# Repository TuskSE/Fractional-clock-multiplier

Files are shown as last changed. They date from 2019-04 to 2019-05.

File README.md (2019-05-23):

# Fractional Clock Multiplier (wip)
8hp algorithmic rhythm-generation module for Eurorack, powered by the Teensy LC

Currently two main modes:
* Fractional Multiplication and division of steady or slowly-varying clock inputs.
  * No requirement for clock input to be multiple ppqn, as the clock input is predictive. I'd like to update this so it can deal with swung input also
* Generation of euclidean rhythms ( see [Toussaint 2005](http://cgm.cs.mcgill.ca/~godfried/publications/banff.pdf) ) from arbitrary (regular or non-regular) clock input 

Output can be shifted either by beat-quantized or subquantized amounts, and optionally recombined with the input. This can be used to generate swung clock output for example, or controlled via CV to generate complex compound rhythms. 

Selectable trigger/gate output modes. 

Assignable CV control over all paramaters, with attenuverter. 

Current schematic, panel mockup and PCB design:

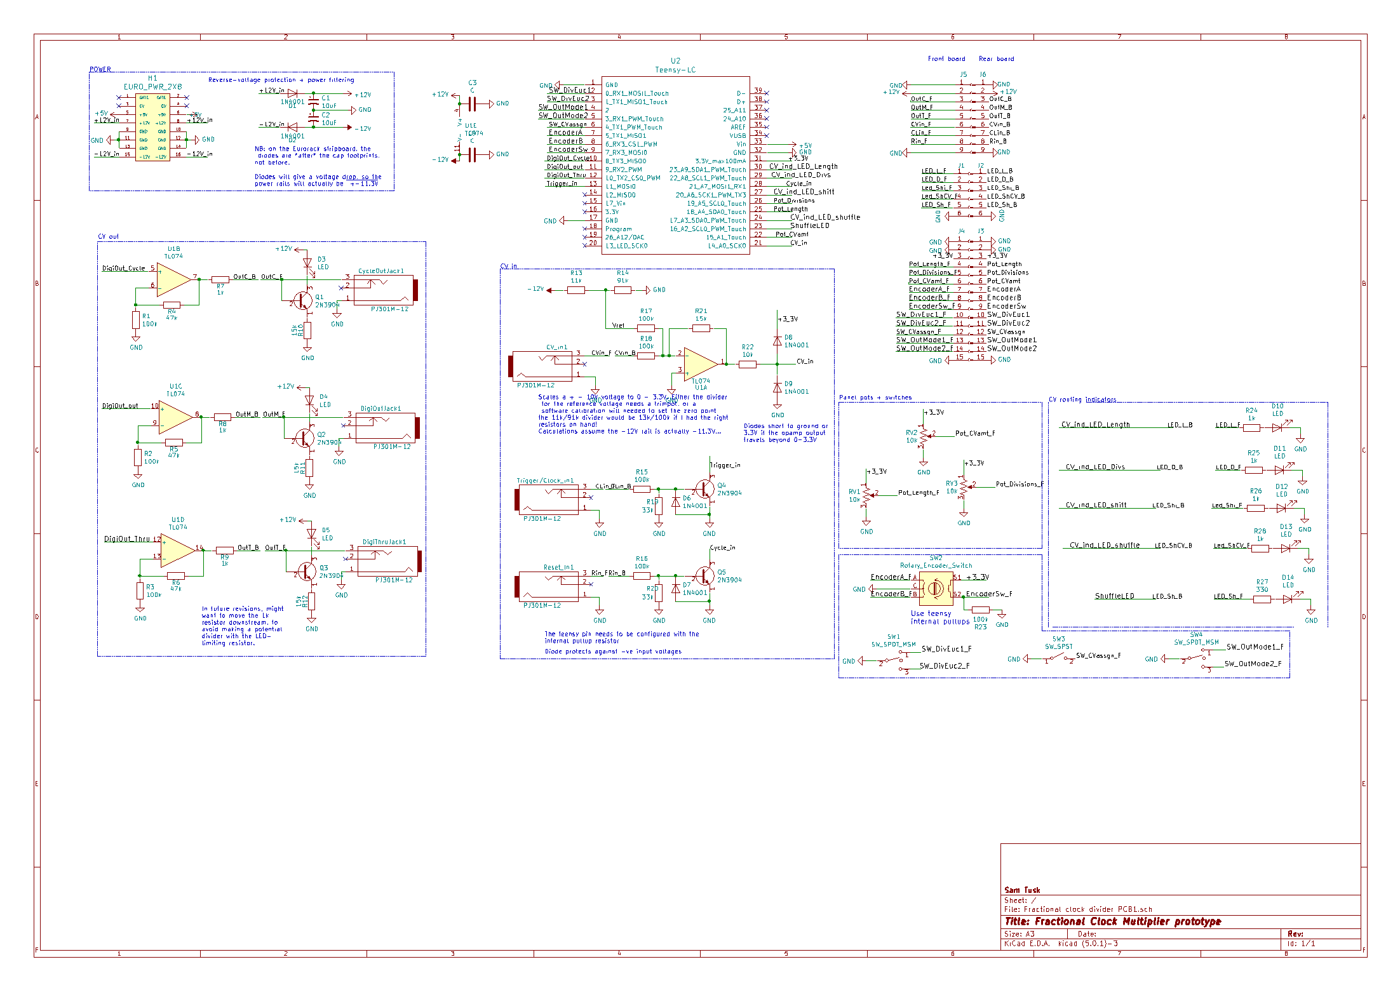
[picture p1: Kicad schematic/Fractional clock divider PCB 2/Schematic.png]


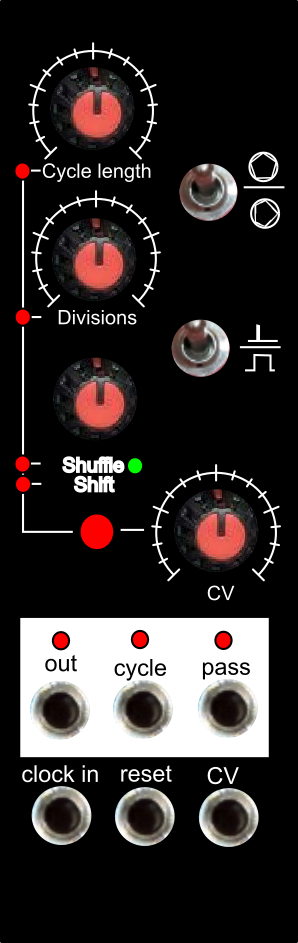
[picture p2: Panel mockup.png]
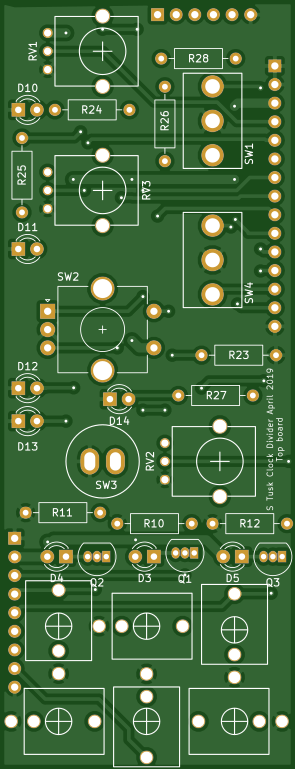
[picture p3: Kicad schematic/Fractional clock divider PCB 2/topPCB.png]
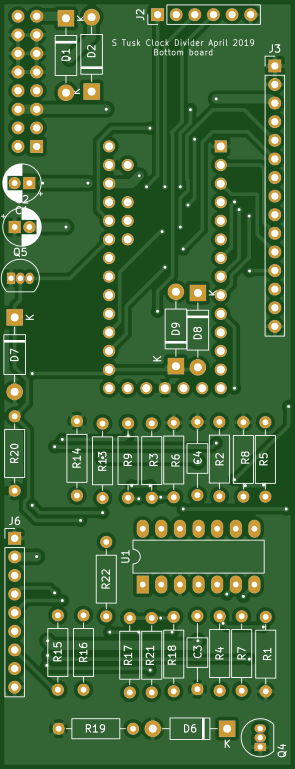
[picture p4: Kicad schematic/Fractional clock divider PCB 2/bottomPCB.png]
   

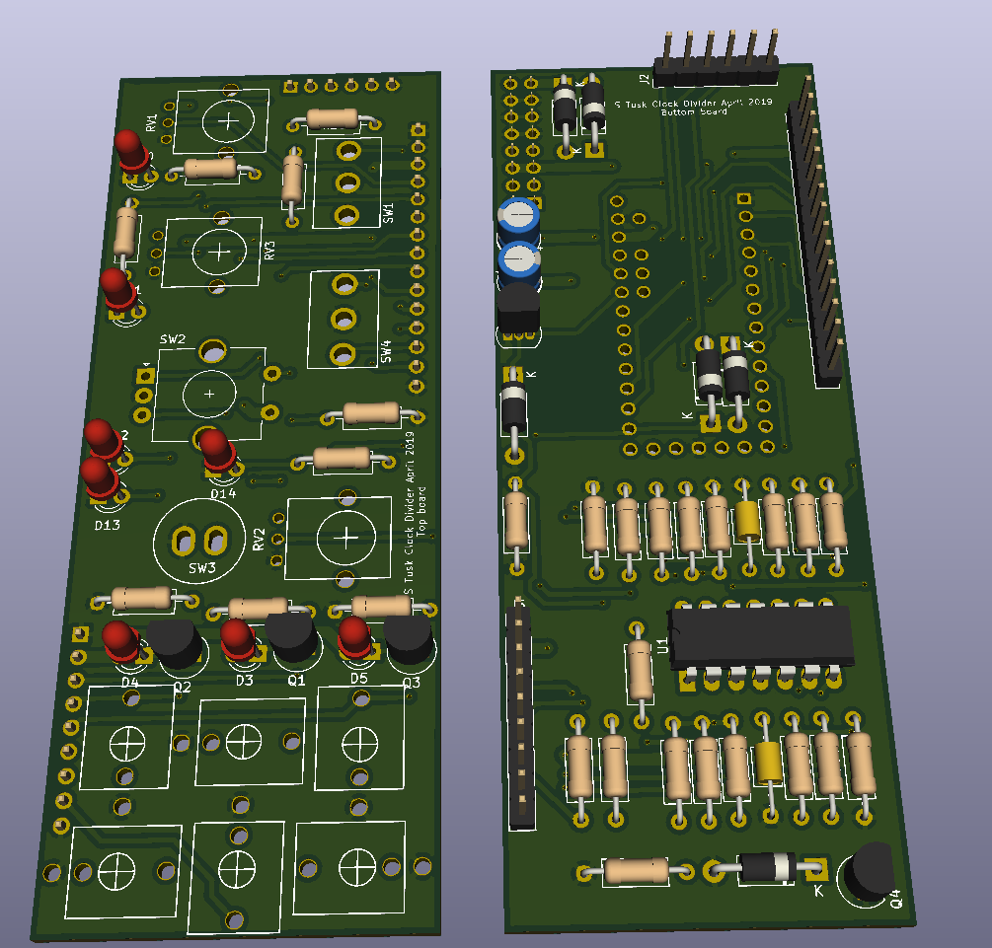
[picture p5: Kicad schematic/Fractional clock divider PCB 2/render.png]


An older prototype:

 


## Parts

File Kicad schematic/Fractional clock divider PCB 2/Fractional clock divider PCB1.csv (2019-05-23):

Id | Designator | Package | Quantity | Designation | Supplier and ref
1 | , | KnobTicks | 2
2 | ,,,, | 9mm alpha jack hole | 5 | 9mm alpha jack hole
3 | ,REF**,REF**,,,,,, | Eurorack Rail Hole | 9 | Eurorack Rail Hole
4 | ,,,,,,, | Eurorack jack hole | 8 | Eurorack jack hole
5 |  | Eurorack LED hole | 1 | Eurorack LED hole
6 | CV_in1,Reset_In1,Trigger/Clock_in1,DigiThruJack1,CycleOutJack1,DigiOutJack1 | PJ301M-12-MoreMetal | 6 | PJ301M-12
7 | Q3,Q1,Q2,Q4,Q5 | TO-92L_HandSolder | 5 | 2N3904
8 | C4,C3 | C_Axial_L3.8mm_D2.6mm_P10.00mm_Horizontal | 2 | 100nF
9 | RV1,RV2,RV3 | Alpha9mmPot | 3 | 10k
10 | R27 | R_Axial_DIN0207_L6.3mm_D2.5mm_P10.16mm_Horizontal | 1 | 330
11 | C1,C2 | CP_Radial_D5.0mm_P2.00mm | 2 | 10uF
12 | D1,D2,D6,D7,D8,D9 | D_DO-41_SOD81_P10.16mm_Horizontal | 6 | 1N4001
13 | D3,D4,D5,D10,D11,D12,D13,D14 | LED_D3.0mm | 8 | LED
14 | H1 | PinSocket_2x08_P2.54mm_Vertical | 1 | EURO_PWR_2X8
15 | J1 | PinHeader_1x06_P2.54mm_Vertical | 1 | Conn_01x06_Female
16 | J2 | PinHeader_1x06_P2.54mm_Vertical | 1 | Conn_01x06_Male
17 | J3 | PinHeader_1x15_P2.54mm_Vertical | 1 | Conn_01x15_Male
18 | J4 | PinHeader_1x15_P2.54mm_Vertical | 1 | Conn_01x15_Female
19 | J5 | PinHeader_1x09_P2.54mm_Vertical | 1 | Conn_01x09_Female
20 | J6 | PinHeader_1x09_P2.54mm_Vertical | 1 | Conn_01x09_Male
21 | R1,R2,R3,R15,R16,R17,R18,R23 | R_Axial_DIN0207_L6.3mm_D2.5mm_P10.16mm_Horizontal | 8 | 100k
22 | R4,R5,R6 | R_Axial_DIN0207_L6.3mm_D2.5mm_P10.16mm_Horizontal | 3 | 47k
23 | R7,R8,R9,R24,R25,R26,R28 | R_Axial_DIN0207_L6.3mm_D2.5mm_P10.16mm_Horizontal | 7 | 1k
24 | R10,R11,R12,R22 | R_Axial_DIN0207_L6.3mm_D2.5mm_P10.16mm_Horizontal | 4 | 10k
25 | R13 | R_Axial_DIN0207_L6.3mm_D2.5mm_P10.16mm_Horizontal | 1 | 11k
26 | R14 | R_Axial_DIN0207_L6.3mm_D2.5mm_P10.16mm_Horizontal | 1 | 91k
27 | R19,R20 | R_Axial_DIN0207_L6.3mm_D2.5mm_P10.16mm_Horizontal | 2 | 33k
28 | R21 | R_Axial_DIN0207_L6.3mm_D2.5mm_P10.16mm_Horizontal | 1 | 15k
29 | SW1,SW4 | SPDT toggle on-off-on | 2 | SW_SPDT_MSM
30 | SW2 | RotaryEncoder_Alps_EC11E-Switch_Vertical_H20mm_CircularMountingHoles | 1 | Rotary_Encoder_Switch
31 | SW3 | SPST momentary push PBS105 | 1 | SW_SPST
32 | U1 | DIP-14_W7.62mm_LongPads | 1 | TL074
33 | U2 | TeensyLC_fixed_pads | 1 | Teensy-LC

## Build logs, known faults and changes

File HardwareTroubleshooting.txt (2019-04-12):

Trigger outs:
- cycle out LED doesn't work, but trigger outs all produce a voltage. The voltage is ~4.88V; will have to check at some point whether this is sufficient for triggering most modules. 

Trig IN triggers much too easily (even with zero input voltage). Tracked down to missing ground collection on the transistor base!

CV in works ok, although at high voltage it starts to clip. I think the offset can be moved, because there's room at the other end of the range. Maybe use a trimmer for the final circuit...

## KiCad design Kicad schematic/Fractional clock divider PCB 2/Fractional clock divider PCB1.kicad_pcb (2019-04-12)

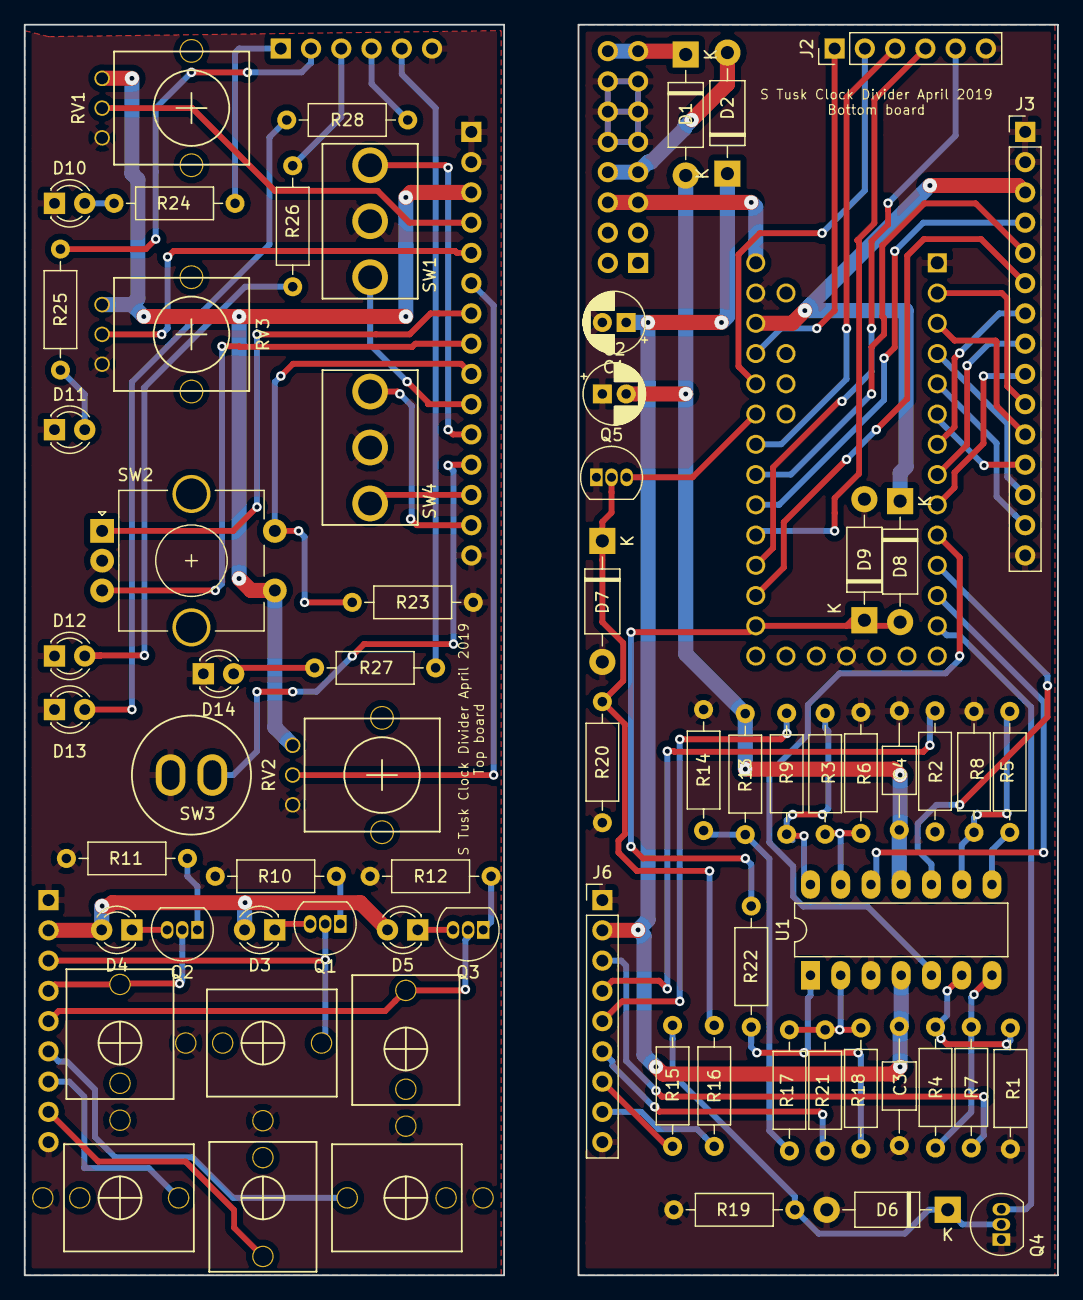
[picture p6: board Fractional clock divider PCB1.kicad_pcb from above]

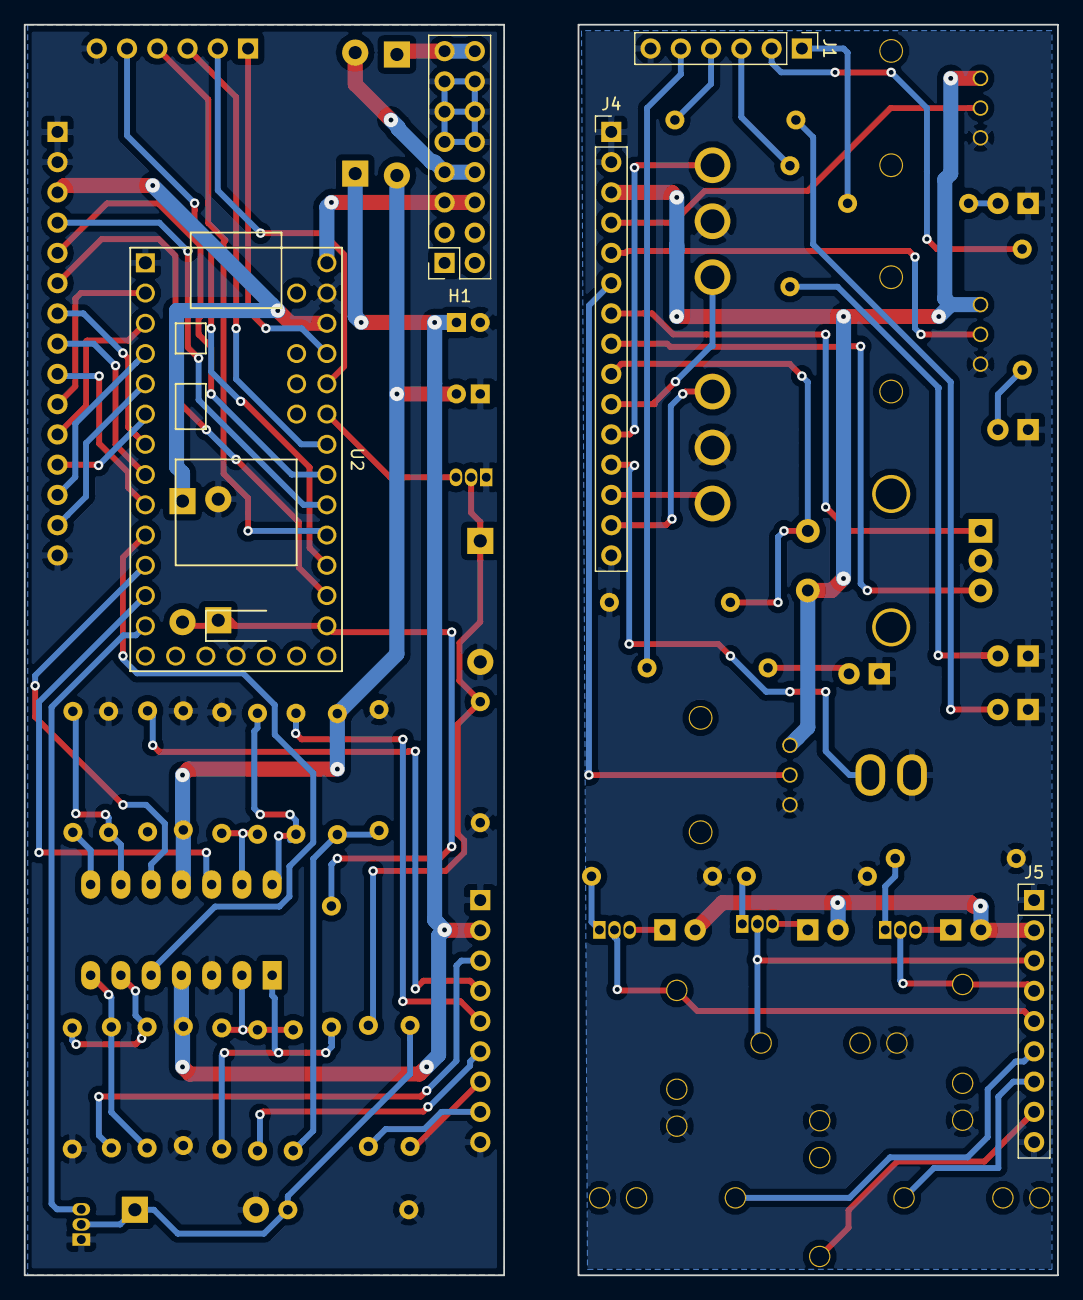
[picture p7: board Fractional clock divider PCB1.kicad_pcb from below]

Board: 2 copper layers, 86.8 x 105.0 mm, 73 parts (5 on the bottom side), 79 nets.

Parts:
C1, C2: 10uF; CP_Radial_D5.0mm_P2.00mm
C3, C4: C; C_Axial_L3.8mm_D2.6mm_P10.00mm_Horizontal
CV_in1: PJ301M-12
CycleOutJack1: PJ301M-12
D1, D2, D6, D7, D8, D9: 1N4001; D_DO-41_SOD81_P10.16mm_Horizontal
D3, D4, D5, D10, D11, D12, D13, D14: LED; LED_D3.0mm
DigiOutJack1: PJ301M-12
DigiThruJack1: PJ301M-12
H1: EURO_PWR_2X8; PinSocket_2x08_P2.54mm_Vertical
J1: Conn_01x06_Female; PinHeader_1x06_P2.54mm_Vertical
J2: Conn_01x06_Male; PinHeader_1x06_P2.54mm_Vertical
J3: Conn_01x15_Male; PinHeader_1x15_P2.54mm_Vertical
J4: Conn_01x15_Female; PinHeader_1x15_P2.54mm_Vertical
J5: Conn_01x09_Female; PinHeader_1x09_P2.54mm_Vertical
J6: Conn_01x09_Male; PinHeader_1x09_P2.54mm_Vertical
Q1, Q2, Q3, Q4, Q5: 2N3904; TO-92_Inline
R1, R2, R3, R15, R16, R17, R18, R23: 100k; R_Axial_DIN0207_L6.3mm_D2.5mm_P10.16mm_Horizontal
R4, R5, R6: 47k; R_Axial_DIN0207_L6.3mm_D2.5mm_P10.16mm_Horizontal
R7, R8, R9, R24, R25, R26, R28: 1k; R_Axial_DIN0207_L6.3mm_D2.5mm_P10.16mm_Horizontal
R10, R11, R12, R21: 15k; R_Axial_DIN0207_L6.3mm_D2.5mm_P10.16mm_Horizontal
R13: 11k; R_Axial_DIN0207_L6.3mm_D2.5mm_P10.16mm_Horizontal
R14: 91k; R_Axial_DIN0207_L6.3mm_D2.5mm_P10.16mm_Horizontal
R19, R20: 33k; R_Axial_DIN0207_L6.3mm_D2.5mm_P10.16mm_Horizontal
R22: 10k; R_Axial_DIN0207_L6.3mm_D2.5mm_P10.16mm_Horizontal
R27: 330; R_Axial_DIN0207_L6.3mm_D2.5mm_P10.16mm_Horizontal
RV1, RV2, RV3: 10k; Alpha9mmPot
Reset_In1: PJ301M-12
SW1, SW4: SW_SPDT_MSM; SPDT toggle on-off-on
SW2: Rotary_Encoder_Switch; RotaryEncoder_Alps_EC11E-Switch_Vertical_H20mm_CircularMoun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
SW3: SW_SPST; SPST momentary push PBS105
Trigger/Clock_in1: PJ301M-12
U1: TL074; DIP-14_W7.62mm_LongPads
U2: Teensy-LC; TeensyLC_fixed_pads

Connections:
+5V: H1.5, H1.6, U2.33
+12V: C1.1, C3.2, D1.1, D3.2, D4.2, D5.2, J5.2, J6.2, U1.4
-12V: C2.2, C4.1, D2.2, R13.2, U1.11
/+3_3V: D8.1, J3.3, J4.3, RV1.1, RV2.1, RV3.1, SW2.S1, U2.31
/+12V_in: D1.2, H1.7, H1.8
/-12V_in: D2.1, H1.15, H1.16
/CLin_B: J6.7, R15.2
/CLin_F: J5.7, Trigger/Clock_in1.3
/CV_in: D8.2, D9.1, R22.1, U2.21
/CV_ind_LED_Divs: J2.2, U2.29
/CV_ind_LED_Length: J2.1, U2.30
/CV_ind_LED_shift: J2.3, U2.27
/CV_ind_LED_shuffle: J2.4, U2.24
/CVin_B: J6.6, R18.2
/CVin_F: CV_in1.3, J5.6
/Cycle_in: Q5.3, U2.28
/DigiOut_Cycle: U1.5, U2.10
/DigiOut_Thru: U1.12, U2.12
/DigiOut_out: U1.10, U2.11
/EncoderA: J3.7, U2.7
/EncoderA_F: J4.7, SW2.A
/EncoderB: J3.8, U2.8
/EncoderB_F: J4.8, SW2.B
/EncoderSw: J3.9, U2.9
/EncoderSw_F: J4.9, R23.1, SW2.S2
/LED_D_F: J1.2, R25.2
/LED_L_F: J1.1, R24.2
/LED_Sh_B: J2.5, U2.23
/LED_Sh_F: J1.5, R27.2
/Led_ShCV_F: J1.4, R28.2
/Led_Shi_F: J1.3, R26.2
/OutC_B: J6.3, R7.1
/OutC_F: CycleOutJack1.3, J5.3, Q1.2
/OutM_B: J6.4, R8.1
/OutM_F: DigiOutJack1.3, J5.4, Q2.2
/OutT_B: J6.5, R9.1
/OutT_F: DigiThruJack1.3, J5.5, Q3.2
/Pot_CVamt: J3.6, U2.22
/Pot_CVamt_F: J4.6, RV2.2
/Pot_Divisions: J3.5, U2.26
/Pot_Divisions_F: J4.5, RV3.2
/Pot_Length: J3.4, U2.25
/Pot_Length_F: J4.4, RV1.2
/Rin_B: J6.8, R16.2
/Rin_F: J5.8, Reset_In1.3
/SW_CVassgn: J3.12, U2.6
/SW_CVassgn_F: J4.12, SW3.2
/SW_DivEuc1: J3.10, U2.2
/SW_DivEuc1_F: J4.10, SW1.1
/SW_DivEuc2: J3.11, U2.3
/SW_DivEuc2_F: J4.11, SW1.3
/SW_OutMode1: J3.13, U2.4
/SW_OutMode1_F: J4.13, SW4.1
/SW_OutMode2: J3.14, U2.5
/SW_OutMode2_F: J4.14, SW4.3
/Trigger_in: Q4.3, U2.13
/Vref: R13.1, R14.2, R17.2
GND: C1.2, C2.1, C3.1, C4.2, CV_in1.1, CycleOutJack1.1, D6.2, D7.2, D9.2, D10.1, D11.1, D12.1, D13.1, D14.1, DigiOutJack1.1, DigiThruJack1.1, H1.9, H1.10, H1.11, H1.12, H1.13, H1.14, J1.6, J2.6, J3.1, J3.2, J3.15, J4.1, J4.2, J4.15, J5.1, J5.9, J6.1, J6.9, Q4.1, Q5.1, R1.2, R2.2, R3.2, R10.1, R11.1, R12.1, R14.1, R19.1, R20.1, R23.2, RV1.3, RV2.3, RV3.3, Reset_In1.1, SW1.2, SW2.C, SW3.1, SW4.2, Trigger/Clock_in1.1, U1.3, U2.1, U2.17, U2.32
unnamed: D3.1, Q1.3
unnamed: D4.1, Q2.3
unnamed: D5.1, Q3.3
unnamed: D6.1, Q4.2, R15.1, R19.2
unnamed: D7.1, Q5.2, R16.1, R20.2
unnamed: D10.2, R24.1
unnamed: D11.2, R25.1
unnamed: D12.2, R26.1
unnamed: D13.2, R28.1
unnamed: D14.2, R27.1
unnamed: Q1.1, R10.2
unnamed: Q2.1, R11.2
unnamed: Q3.1, R12.2
unnamed: R1.1, R4.2, U1.6
unnamed: R2.1, R5.2, U1.9
unnamed: R3.1, R6.2, U1.13
unnamed: R4.1, R7.2, U1.7
unnamed: R5.1, R8.2, U1.8
unnamed: R6.1, R9.2, U1.14
unnamed: R17.1, R18.1, R21.2, U1.2
unnamed: R21.1, R22.2, U1.1

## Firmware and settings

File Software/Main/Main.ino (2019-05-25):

#include <Metro.h> // Include the Metro library
#include <Encoder.h>
const int KnobCalibrateMode = 0;

//Define all the pins
const int SwPin_DivEuc = 0;  // Low input = switch in upper position
const int SwPin_DivEuc2 = 1;   // Low input = switch in lower position
const int SwPin_OutModes = 2;   // Low input = switch in upper position
const int SwPin_OutModes2 = 3;  // Low input = switch in lower position
const int SwPin_CVassign = 4;   //Low input = switch pressed
const int SwPin_Encoder = 7;
const int CtrPin_CVamt = 15;
const int CtrPin_Divisions = 19;
const int CtrPin_Length = 18;
const int OutPin_Cycle = 8;
const int OutPin_MainOut = 9;
const int OutPin_Thru = 10;
const int InPin_Trig = 11; //Low input voltage = HIGH reading on pin.
const int InPin_CV = 14;
const int InPin_Reset = 21;
const int LEDPin_Shuffle = 16;
const int LEDPin_CV_ind_Length = 23;
const int LEDPin_CV_ind_Divs = 22;
const int LEDPin_CV_ind_Shift = 17;
const int LEDPin_CV_ind_Shuffle = 20;
//const int LEDPin_internal = 13;
const int EncPinA = 5;
const int EncPinB = 6;

//recentPresses[] stores the times of the 6 most recent switch presses
//[0] = most recent, [5] = most distant
// every time we write to this, shuffle the array around
double recentClockTimes[6] = {0,0,0,0,0,0}; 
const int recentClockTimesArraySize = 6;

const double ButtonPressTimeout = 5000000; //in microseconds. if the time between two button presses is greater than this, do not use it to set the output clock. 

//sets the range for the Length and Division knobs
const int Divisions_min = 0;
const int Divisions_max = 16;
const int Length_min = 0;
const int Length_max = 16;
//To read Knob value: reading = map(analogRead(CtrPin_Length),0,1023,Length_min,Length_max);
const int LengthKnobLUTDividers[] = {33, 177, 411, 667, 919, 1178, 1474, 1784, 2113, 2443, 2743, 3012, 3276, 3552, 3835, 4032, 2060};
int ControlVoltage_in = 0;
int ControlValue_Divisions, ControlValue_Divisions_Scaled = 1;
int ControlValue_Length, ControlValue_Length_Scaled =1;

double pressTimeTemp = 0; //temporarily stores the time, when the button is pressed
int clockInState = 0;
int clockInPrevState = 0; // this will remember if the clock input was "on" in the previous cycle 
int resetInState = 0;
int resetInPrevState = 0;

//multiplication/division factors. These will eventually be controlled by pots.
//float ClicksPerCycle = 8;
float MultDivFactor2 = 2;
float MultDivFactor3 = 0.5;

Encoder EncKnob(EncPinB, EncPinA);
int EncoderValTemp = 0;
int EncoderShiftInstruction = 0; 
int intEncoderShuffleInstruction = 0;
float EncoderShuffleInstruction = 0.0;
const int EncoderCountsPerClick = 4; //property of the encoder used: how many digital output counts corresponding to one click (indent) felt by the user.
//const int EncoderClicksPerRevolution = 20; //property of the encoder used 
int EncoderShuffleNoOfClicks = 20; //The number of clicks of encoder rotation which makes the shuffle amount return to it's starting value
const int EncoderShuffleLedLUT[] = {0, 1, 1, 2, 3, 4, 5, 6, 7, 8, 9, 11, 13, 15, 17, 20, 23, 25, 30, 30, 20}; 
int intShuffleCVInstruction = 0;
int ShiftCVInstruction = 0;

bool CVcontrolCycleLength, CVcontrolDivisions, CVcontrolShuffle, CVcontrolShift;

bool EuclideanMode_temp = true; //if 0, runs as clock divider. If 1, runs as euclidean pattern generator. 

int Temp;

//lookup tables for pot readings
const int LUT_L[] = {120,120,120,120,120,120,120,120,120,120,120,120,120,120,120,120,120,120,120,120,120,120,120,120,120,120,120,361,361,361,361,361,361,361,361,361,361,361,361,361,361,361,361,361,361,361,361,361,361,361,361,361,361,361,361,361,361,361,361,361,361,361,361,361,361,361,361,361,361,361,361,361,361,361,361,361,361,361,361,361,361,361,361,361,361,361,361,361,361,361,361,361,361,361,361,361,361,361,361,361,361,361,361,361,361,361,361,361,361,361,361,361,361,361,361,361,361,361,361,361,361,361,361,361,361,361,361,361,361,361,361,361,361,361,361,361,361,361,361,361,361,361,361,361,602,602,602,602,602,602,602,602,602,602,602,602,602,602,602,602,602,602,602,602,602,602,602,602,602,602,602,602,602,602,602,602,602,602,602,602,602,602,602,602,602,602,602,602,602,602,602,602,602,602,602,602,602,602,602,602,602,602,602,602,602,602,602,602,602,602,602,602,602,602,602,602,602,602,602,602,602,602,602,602,602,602,602,602,602,602,602,602,602,602,602,602,602,602,602,602,602,602,602,602,602,602,602,602,602,602,602,602,602,602,602,602,602,602,602,602,602,602,602,602,602,602,602,602,602,602,602,602,602,602,602,602,602,602,602,602,602,602,602,602,602,602,602,602,602,602,602,602,602,602,602,602,602,602,602,602,602,602,602,602,602,602,602,602,602,602,602,602,602,602,602,602,602,602,602,602,602,602,602,602,602,602,602,602,602,602,602,602,602,602,602,602,602,602,602,602,602,602,602,602,602,602,602,602,602,602,602,602,602,602,602,602,602,602,602,602,602,602,602,602,602,602,602,602,602,602,602,602,602,602,602,602,602,602,843,843,843,843,843,843,843,843,843,843,843,843,843,843,843,843,843,843,843,843,843,843,843,843,843,843,843,843,843,843,843,843,843,843,843,843,843,843,843,843,843,843,843,843,843,843,843,843,843,843,843,843,843,843,843,843,843,843,843,843,843,843,843,843,843,843,843,843,843,843,843,843,843,843,843,843,843,843,843,843,843,843,843,843,843,843,843,843,843,843,843,843,843,843,843,843,843,843,843,843,843,843,843,843,843,843,843,843,843,843,843,843,843,843,843,843,843,843,843,843,843,843,843,843,843,843,843,843,843,843,843,843,843,843,843,843,843,843,843,843,843,843,843,843,843,843,843,843,843,843,843,843,843,843,843,843,843,843,843,843,843,843,843,843,843,843,843,843,843,843,843,843,843,843,843,843,843,843,843,843,843,843,843,843,843,843,843,843,843,843,843,843,843,843,843,843,843,843,843,843,843,843,843,843,843,843,843,843,843,843,843,843,843,843,843,843,843,843,843,843,843,843,843,843,843,843,843,843,843,843,843,843,843,843,843,843,843,843,843,843,843,843,843,843,843,843,843,843,843,843,843,843,843,843,843,843,843,843,843,843,843,843,843,843,843,843,843,843,843,843,843,843,843,1084,1084,1084,1084,1084,1084,1084,1084,1084,1084,1084,1084,1084,1084,1084,1084,1084,1084,1084,1084,1084,1084,1084,1084,1084,1084,1084,1084,1084,1084,1084,1084,1084,1084,1084,1084,1084,1084,1084,1084,1084,1084,1084,1084,1084,1084,1084,1084,1084,1084,1084,1084,1084,1084,1084,1084,1084,1084,1084,1084,1084,1084,1084,1084,1084,1084,1084,1084,1084,1084,1084,1084,1084,1084,1084,1084,1084,1084,1084,1084,1084,1084,1084,1084,1084,1084,1084,1084,1084,1084,1084,1084,1084,1084,1084,1084,1084,1084,1084,1084,1084,1084,1084,1084,1084,1084,1084,1084,1084,1084,1084,1084,1084,1084,1084,1084,1084,1084,1084,1084,1084,1084,1084,1084,1084,1084,1084,1084,1084,1084,1084,1084,1084,1084,1084,1084,1084,1084,1084,1084,1084,1084,1084,1084,1084,1084,1084,1084,1084,1084,1084,1084,1084,1084,1084,1084,1084,1084,1084,1084,1084,1084,1084,1084,1084,1084,1084,1084,1084,1084,1084,1084,1084,1084,1084,1084,1084,1084,1084,1084,1084,1084,1084,1084,1084,1084,1084,1084,1084,1084,1084,1084,1084,1084,1084,1084,1084,1084,1084,1084,1084,1084,1084,1084,1084,1084,1084,1084,1084,1084,1084,1084,1084,1084,1084,1084,1084,1084,1084,1084,1084,1084,1084,1084,1084,1084,1084,1084,1084,1084,1084,1084,1084,1084,1084,1084,1084,1084,1084,1084,1084,1084,1084,1084,1084,1084,1084,1084,1084,1084,1084,1084,1084,1084,1084,1084,1084,1084,1084,1084,1084,1325,1325,1325,1325,1325,1325,1325,1325,1325,1325,1325,1325,1325,1325,1325,1325,1325,1325,1325,1325,1325,1325,1325,1325,1325,1325,1325,1325,1325,1325,1325,1325,1325,1325,1325,1325,1325,1325,1325,1325,1325,1325,1325,1325,1325,1325,1325,1325,1325,1325,1325,1325,1325,1325,1325,1325,1325,1325,1325,1325,1325,1325,1325,1325,1325,1325,1325,1325,1325,1325,1325,1325,1325,1325,1325,1325,1325,1325,1325,1325,1325,1325,1325,1325,1325,1325,1325,1325,1325,1325,1325,1325,1325,1325,1325,1325,1325,1325,1325,1325,1325,1325,1325,1325,1325,1325,1325,1325,1325,1325,1325,1325,1325,1325,1325,1325,1325,1325,1325,1325,1325,1325,1325,1325,1325,1325,1325,1325,1325,1325,1325,1325,1325,1325,1325,1325,1325,1325,1325,1325,1325,1325,1325,1325,1325,1325,1325,1325,1325,1325,1325,1325,1325,1325,1325,1325,1325,1325,1325,1325,1325,1325,1325,1325,1325,1325,1325,1325,1325,1325,1325,1325,1325,1325,1325,1325,1325,1325,1325,1325,1325,1325,1325,1325,1325,1325,1325,1325,1325,1325,1325,1325,1325,1325,1325,1325,1325,1325,1325,1325,1325,1325,1325,1325,1325,1325,1325,1325,1325,1325,1325,1325,1325,1325,1325,1325,1325,1325,1325,1325,1325,1325,1325,1325,1325,1325,1325,1325,1325,1325,1325,1325,1325,1325,1325,1325,1325,1325,1325,1325,1325,1325,1325,1325,1325,1325,1325,1325,1325,1325,1325,1325,1325,1325,1325,1325,1325,1325,1325,1325,1325,1325,1325,1325,1325,1325,1566,1566,1566,1566,1566,1566,1566,1566,1566,1566,1566,1566,1566,1566,1566,1566,1566,1566,1566,1566,1566,1566,1566,1566,1566,1566,1566,1566,1566,1566,1566,1566,1566,1566,1566,1566,1566,1566,1566,1566,1566,1566,1566,1566,1566,1566,1566,1566,1566,1566,1566,1566,1566,1566,1566,1566,1566,1566,1566,1566,1566,1566,1566,1566,1566,1566,1566,1566,1566,1566,1566,1566,1566,1566,1566,1566,1566,1566,1566,1566,1566,1566,1566,1566,1566,1566,1566,1566,1566,1566,1566,1566,1566,1566,1566,1566,1566,1566,1566,1566,1566,1566,1566,1566,1566,1566,1566,1566,1566,1566,1566,1566,1566,1566,1566,1566,1566,1566,1566,1566,1566,1566,1566,1566,1566,1566,1566,1566,1566,1566,1566,1566,1566,1566,1566,1566,1566,1566,1566,1566,1566,1566,1566,1566,1566,1566,1566,1566,1566,1566,1566,1566,1566,1566,1566,1566,1566,1566,1566,1566,1566,1566,1566,1566,1566,1566,1566,1566,1566,1566,1566,1566,1566,1566,1566,1566,1566,1566,1566,1566,1566,1566,1566,1566,1566,1566,1566,1566,1566,1566,1566,1566,1566,1566,1566,1566,1566,1566,1566,1566,1566,1566,1566,1566,1566,1566,1566,1566,1566,1566,1566,1566,1566,1566,1566,1566,1566,1566,1566,1566,1566,1566,1566,1566,1566,1566,1566,1566,1566,1566,1566,1566,1566,1566,1566,1566,1566,1566,1566,1566,1566,1566,1566,1566,1566,1566,1566,1566,1566,1566,1566,1566,1566,1566,1566,1566,1566,1566,1566,1566,1566,1566,1566,1566,1566,1566,1566,1566,1566,1566,1566,1566,1566,1566,1566,1566,1566,1566,1566,1566,1566,1566,1566,1566,1566,1566,1566,1566,1566,1566,1566,1807,1807,1807,1807,1807,1807,1807,1807,1807,1807,1807,1807,1807,1807,1807,1807,1807,1807,1807,1807,1807,1807,1807,1807,1807,1807,1807,1807,1807,1807,1807,1807,1807,1807,1807,1807,1807,1807,1807,1807,1807,1807,1807,1807,1807,1807,1807,1807,1807,1807,1807,1807,1807,1807,1807,1807,1807,1807,1807,1807,1807,1807,1807,1807,1807,1807,1807,1807,1807,1807,1807,1807,1807,1807,1807,1807,1807,1807,1807,1807,1807,1807,1807,1807,1807,1807,1807,1807,1807,1807,1807,1807,1807,1807,1807,1807,1807,1807,1807,1807,1807,1807,1807,1807,1807,1807,1807,1807,1807,1807,1807,1807,1807,1807,1807,1807,1807,1807,1807,1807,1807,1807,1807,1807,1807,1807,1807,1807,1807,1807,1807,1807,1807,1807,1807,1807,1807,1807,1807,1807,1807,1807,1807,1807,1807,1807,1807,1807,1807,1807,1807,1807,1807,1807,1807,1807,1807,1807,1807,1807,1807,1807,1807,1807,1807,1807,1807,1807,1807,1807,1807,1807,1807,1807,1807,1807,1807,1807,1807,1807,1807,1807,1807,1807,1807,1807,1807,1807,1807,1807,1807,1807,1807,1807,1807,1807,1807,1807,1807,1807,1807,1807,1807,1807,1807,1807,1807,1807,1807,1807,1807,1807,1807,1807,1807,1807,1807,1807,1807,1807,1807,1807,1807,1807,1807,1807,1807,1807,1807,1807,1807,1807,1807,1807,1807,1807,1807,1807,1807,1807,1807,1807,1807,1807,1807,1807,1807,1807,1807,1807,1807,1807,1807,1807,1807,1807,1807,1807,1807,1807,1807,1807,1807,1807,1807,1807,1807,1807,1807,1807,1807,1807,1807,1807,1807,1807,1807,1807,1807,1807,1807,1807,1807,1807,1807,1807,1807,1807,1807,1807,1807,1807,1807,1807,1807,1807,1807,1807,1807,1807,1807,1807,1807,1807,1807,1807,1807,1807,1807,1807,1807,1807,1807,1807,1807,1807,1807,1807,1807,1807,1807,1807,2048,2048,2048,2048,2048,2048,2048,2048,2048,2048,2048,2048,2048,2048,2048,2048,2048,2048,2048,2048,2048,2048,2048,2048,2048,2048,2048,2048,2048,2048,2048,2048,2048,2048,2048,2048,2048,2048,2048,2048,2048,2048,2048,2048,2048,2048,2048,2048,2048,2048,2048,2048,2048,2048,2048,2048,2048,2048,2048,2048,2048,2048,2048,2048,2048,2048,2048,2048,2048,2048,2048,2048,2048,2048,2048,2048,2048,2048,2048,2048,2048,2048,2048,2048,2048,2048,2048,2048,2048,2048,2048,2048,2048,2048,2048,2048,2048,2048,2048,2048,2048,2048,2048,2048,2048,2048,2048,2048,2048,2048,2048,2048,2048,2048,2048,2048,2048,2048,2048,2048,2048,2048,2048,2048,2048,2048,2048,2048,2048,2048,2048,2048,2048,2048,2048,2048,2048,2048,2048,2048,2048,2048,2048,2048,2048,2048,2048,2048,2048,2048,2048,2048,2048,2048,2048,2048,2048,2048,2048,2048,2048,2048,2048,2048,2048,2048,2048,2048,2048,2048,2048,2048,2048,2048,2048,2048,2048,2048,2048,2048,2048,2048,2048,2048,2048,2048,2048,2048,2048,2048,2048,2048,2048,2048,2048,2048,2048,2048,2048,2048,2048,2048,2048,2048,2048,2048,2048,2048,2048,2048,2048,2048,2048,2048,2048,2048,2048,2048,2048,2048,2048,2048,2048,2048,2048,2048,2048,2048,2048,2048,2048,2048,2048,2048,2048,2048,2048,2048,2048,2048,2048,2048,2048,2048,2048,2048,2048,2048,2048,2048,2048,2048,2048,2048,2048,2048,2048,2048,2048,2048,2048,2048,2048,2048,2048,2048,2048,2048,2048,2048,2048,2048,2048,2048,2048,2048,2048,2048,2048,2048,2048,2048,2048,2048,2048,2048,2048,2048,2048,2048,2048,2048,2048,2048,2048,2048,2048,2048,2048,2048,2048,2048,2048,2048,2048,2048,2048,2048,2048,2048,2048,2048,2048,2048,2048,2048,2048,2048,2048,2048,2048,2048,2048,2048,2048,2048,2048,2048,2289,2289,2289,2289,2289,2289,2289,2289,2289,2289,2289,2289,2289,2289,2289,2289,2289,2289,2289,2289,2289,2289,2289,2289,2289,2289,2289,2289,2289,2289,2289,2289,2289,2289,2289,2289,2289,2289,2289,2289,2289,2289,2289,2289,2289,2289,2289,2289,2289,2289,2289,2289,2289,2289,2289,2289,2289,2289,2289,2289,2289,2289,2289,2289,2289,2289,2289,2289,2289,2289,2289,2289,2289,2289,2289,2289,2289,2289,2289,2289,2289,2289,2289,2289,2289,2289,2289,2289,2289,2289,2289,2289,2289,2289,2289,2289,2289,2289,2289,2289,2289,2289,2289,2289,2289,2289,2289,2289,2289,2289,2289,2289,2289,2289,2289,2289,2289,2289,2289,2289,2289,2289,2289,2289,2289,2289,2289,2289,2289,2289,2289,2289,2289,2289,2289,2289,2289,2289,2289,2289,2289,2289,2289,2289,2289,2289,2289,2289,2289,2289,2289,2289,2289,2289,2289,2289,2289,2289,2289,2289,2289,2289,2289,2289,2289,2289,2289,2289,2289,2289,2289,2289,2289,2289,2289,2289,2289,2289,2289,2289,2289,2289,2289,2289,2289,2289,2289,2289,2289,2289,2289,2289,2289,2289,2289,2289,2289,2289,2289,2289,2289,2289,2289,2289,2289,2289,2289,2289,2289,2289,2289,2289,2289,2289,2289,2289,2289,2289,2289,2289,2289,2289,2289,2289,2289,2289,2289,2289,2289,2289,2289,2289,2289,2289,2289,2289,2289,2289,2289,2289,2289,2289,2289,2289,2289,2289,2289,2289,2289,2289,2289,2289,2289,2289,2289,2289,2289,2289,2289,2289,2289,2289,2289,2289,2289,2289,2289,2289,2289,2289,2289,2289,2289,2289,2289,2289,2289,2289,2289,2289,2289,2289,2289,2289,2289,228
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
void loop() {

  //calibrate mode only
  if(KnobCalibrateMode == 1){
      KnobCalibrator LengthKnobCalibrator, DivsKnobCalibrator;
      LengthKnobCalibrator.SetKnobPin(CtrPin_Length);
      DivsKnobCalibrator.SetKnobPin(CtrPin_Divisions);
      Serial.println("Length knob:");
      LengthKnobCalibrator.RecordCalibrationValues();
      Serial.println("Divs knob:");
      DivsKnobCalibrator.RecordCalibrationValues();
  }

  //Check mode
  ModeControllerMaster.ReadModeSwitch();
  ModeControllerMaster.ReadGateSwitch();
  
  // deal with reset input
  resetInState = digitalRead(InPin_Reset);
  if(resetInState == 0 && resetInPrevState == 1){      //............if the Reset In voltage switches from low to high
    //pass to whatever's controlling the current output mode
      EuclideanCalculatorMain.CycleReset();
      DividerMultiplierMain.CycleReset();
  }
    resetInPrevState = resetInState;    
    
  // deal with clock input
  clockInState = digitalRead(InPin_Trig);
  if(clockInState == 0 && clockInPrevState == 1){      //............if the Trigger In voltage switches from low to high
    //pass to the pulse predictor
    InputPulsePredictor.InputPulse();

    //pass to the output calculators
      EuclideanCalculatorMain.InputPulse();
      DividerMultiplierMain.InputPulse();
  }
    clockInPrevState = clockInState;



  


  //update knob control values
  //we repeat the reading twice, because if we take the first reading, it will still have some residual influence from the previous reading because the capacitor hasn't had time to charge/discharge. 
  ControlValue_Length = analogRead(CtrPin_Length);
  //ControlValue_Length = JitterSmootherL.SmoothChanges(analogRead(CtrPin_Length));
  ControlValue_Length = LUT_L[JitterSmootherL.SmoothChanges(analogRead(CtrPin_Length))];
  ControlValue_Divisions = analogRead(CtrPin_Divisions);
  //ControlValue_Divisions = JitterSmootherD.SmoothChanges(analogRead(CtrPin_Divisions));
  ControlValue_Divisions = LUT_D[JitterSmootherD.SmoothChanges(analogRead(CtrPin_Divisions))];

  //add control voltage to knob value as appriate
  //Prevent the voltage from pushing the control value beyond the normal range of the knob. 
  if (CVcontrolCycleLength == true){
    ControlValue_Length = ControlValue_Length + CVassignerMaster.readCV();
    if(ControlValue_Length < 0){ControlValue_Length = 0;}
    if(ControlValue_Length > 4096){ControlValue_Length = 4096;}
  }
  
  if(CVcontrolDivisions == true){
    ControlValue_Divisions = ControlValue_Divisions + CVassignerMaster.readCV();
    if(ControlValue_Divisions < 0){ControlValue_Divisions = 0;}
    if(ControlValue_Divisions > 4096){ControlValue_Divisions = 4096;}
  }

  //scale control values to be within specified range
  ControlValue_Length_Scaled = map(ControlValue_Length,0,4096,Length_min,Length_max);
  ControlValue_Divisions_Scaled = map(ControlValue_Divisions,0,4096,Divisions_min,Divisions_max);
  
  //For now, don't permit "length" to be 0, as I'm not sure what we would do with that result!
  if(ControlValue_Length_Scaled == 0){
    ControlValue_Length_Scaled = 1;
  }
  
  //check if the encoder has been turned since the last cycle
  EncoderValTemp = -EncKnob.read();

  //If the encoder has been turned, update values accordingly
  if (EncoderValTemp !=  0){
    if((EncoderValTemp % EncoderCountsPerClick) == 0){  //if this is not true, the knob has not reached an indent yet and must be mid-turn - do nothing     
      if(digitalRead(SwPin_Encoder)==0){
         //if the encoder switch was *not* pushed, we update a shift paramater. This will be fed to the Shift function after any control voltage is added
         EncoderShiftInstruction = (int)EncoderValTemp/EncoderCountsPerClick;
      } else if(digitalRead(SwPin_Encoder)==1){
         //if the encoder switch *was* pushed, update a shuffle paramater 
         intEncoderShuffleInstruction = -EncoderValTemp/EncoderCountsPerClick;
      }
      EncKnob.write(0); //Now that we have read the accumulated value from the encoder, reset encoder reading to zero
    }
  }

  //Calculate any CV effects on shift or shuffle
  intShuffleCVInstruction = CVassignerMaster.ReturnIntShuffleModifier();
  ShiftCVInstruction = CVassignerMaster.ReturnShiftModifier();

  //Apply knob+CV changes, including Shift/Shuffle, to output calculations
     EuclideanCalculatorMain.UpdateKnobValues(ControlValue_Length_Scaled, ControlValue_Divisions_Scaled, intEncoderShuffleInstruction + intShuffleCVInstruction, 0);
     EuclideanCalculatorMain.ShiftPositionInInputCycle(EncoderShiftInstruction + ShiftCVInstruction);
     DividerMultiplierMain.UpdateKnobValues(ControlValue_Length_Scaled, ControlValue_Divisions_Scaled);
     DividerMultiplierMain.ShiftPositionInInputCycle(EncoderShiftInstruction + ShiftCVInstruction);
     DividerMultiplierMain.UpdateIntShuffleTime(intEncoderShuffleInstruction + intShuffleCVInstruction);
      

  //reset temporary variables
  EncoderShiftInstruction = 0; 
  intEncoderShuffleInstruction = 0;
  intShuffleCVInstruction = 0;
  ShiftCVInstruction = 0;
  
  //update routing of CV signals
  CVassignerMaster.CheckButton();
  
  // deal with starting output pulses
  //for gate output mode, we need to tell the trigger manager to finish emitting pulse(gate) only if a Thru trigger is signalled without an accompanying main trigger
    // ask euclidean generator whether we should output a pulse
    if(EuclideanCalculatorMain.ShouldWeOutputThruPulse()==true && ModeControllerMaster.AreWeInEuclideanMode()){
        TrigOutManager_Thru.StartPulse();
        TrigOutManager_Main.EndPulse();
      }
    
      if(EuclideanCalculatorMain.ShouldWeOutputCyclePulse()==true && ModeControllerMaster.AreWeInEuclideanMode()){
        TrigOutManager_Cycle.StartPulse();
      }
    
      if(EuclideanCalculatorMain.ShouldWeOutputMainPulse()==true && ModeControllerMaster.AreWeInEuclideanMode()){
        TrigOutManager_Thru.StartPulse();
        TrigOutManager_Main.StartPulse();
      }
  
      if(DividerMultiplierMain.ShouldWeOutputThruPulse()==true && ModeControllerMaster.AreWeInDividerMultiplierMode()){
        TrigOutManager_Thru.StartPulse();
        TrigOutManager_Main.EndPulse();
        TrigOutManager_Main.EndPulse();
      }
    
      if(DividerMultiplierMain.ShouldWeOutputCyclePulse()==true && ModeControllerMaster.AreWeInDividerMultiplierMode()){
        TrigOutManager_Cycle.StartPulse();
      }
    
      if(DividerMultiplierMain.ShouldWeOutputMainPulse()==true && ModeControllerMaster.AreWeInDividerMultiplierMode()){
        TrigOutManager_Thru.StartPulse();
        TrigOutManager_Main.EndPulse();
        TrigOutManager_Main.StartPulse();
      }
    
  //deal with actually setting voltage on the outputs
  if(TrigOutManager_Thru.ShouldWeBeOutputting(false)==true){
    digitalWrite(OutPin_Thru,HIGH);
  } else {
    digitalWrite(OutPin_Thru,LOW);
  }

  if(TrigOutManager_Main.ShouldWeBeOutputting(ModeControllerMaster.AreWeInMainOutputGateMode())){
    digitalWrite(OutPin_MainOut,HIGH);
  } else {
    digitalWrite(OutPin_MainOut,LOW);
  }

  if(TrigOutManager_Cycle.ShouldWeBeOutputting(false)==true){
    digitalWrite(OutPin_Cycle,HIGH);
  } else {
    digitalWrite(OutPin_Cycle,LOW);
  }


}

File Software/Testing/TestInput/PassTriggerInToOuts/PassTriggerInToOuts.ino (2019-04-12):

#include <Metro.h> // Include the Metro library

//Define all the pins
const int SwPin_DivEuc = 0;
const int SwPin_OutModes = 1;
const int SwPin_CVup = 2;
const int SwPin_CVdown = 3;
const int SwPin_Encoder = 6;
const int CtrPin_CVamt = 21;
const int CtrPin_Divisions = 20;
const int CtrPin_Length = 19;
const int EncPinA = 4;
const int EncPinB = 5;
const int OutPin_Cycle = 7;
const int OutPin_MainOut = 8;
const int OutPin_Thru = 9;
const int InPin_Trig = 18; //Low input voltage = HIGH reading on pin.
const int InPin_CV = 17;
const int LEDPin_Shuffle = 16;
const int LEDPin_internal = 13;

//recentPresses[] stores the times of the 6 most recent switch presses
//[0] = most recent, [5] = most distant
// every time we write to this, shuffle the array around
double recentClockTimes[6] = {0,0,0,0,0,0}; 
const int recentClockTimesArraySize = 6;

const double ButtonPressTimeout = 5000000; //in microseconds. if the time between two button presses is greater than this, do not use it to set the output clock. 

double pressTimeTemp = 0; //temporarily stores the time, when the button is pressed
int clockInPrevState = 0; // this will remember if the clock input was "on" in the previous cycle 

//multiplication/division factors. These will eventually be controlled by pots.
//float ClicksPerCycle = 8;
float MultDivFactor2 = 1;
float MultDivFactor3 = 1;

void setup() {
  // put your setup code here, to run once:
  
  //Configure pins
  pinMode(SwPin_DivEuc,INPUT_PULLUP);
  pinMode(SwPin_OutModes,INPUT_PULLUP);
  pinMode(SwPin_CVup,INPUT_PULLUP);
  pinMode(SwPin_CVdown,INPUT_PULLUP);
  pinMode(SwPin_Encoder,INPUT);

  pinMode(EncPinA,INPUT_PULLUP);
  pinMode(EncPinB,INPUT_PULLUP);
  
  pinMode(CtrPin_CVamt,INPUT);
  pinMode(CtrPin_Divisions,INPUT);
  pinMode(CtrPin_Length,INPUT);

  pinMode(OutPin_Cycle,OUTPUT);
  pinMode(OutPin_MainOut,OUTPUT);
  pinMode(OutPin_Thru,OUTPUT);
  pinMode(LEDPin_Shuffle,OUTPUT);
  pinMode(LEDPin_internal,OUTPUT);

  pinMode(InPin_Trig,INPUT_PULLUP);
  pinMode(InPin_CV,INPUT);
}

void loop() {
  // put your main code here, to run repeatedly:

  // deal with input
  if(digitalRead(InPin_Trig) == 0){      //............if the switch turns from off to on
    digitalWrite(OutPin_Thru,HIGH);
    digitalWrite(OutPin_MainOut,HIGH);
    digitalWrite(OutPin_Cycle,HIGH);
  }
  else{
    digitalWrite(OutPin_Thru,LOW);
    digitalWrite(OutPin_MainOut,LOW);
    digitalWrite(OutPin_Cycle,LOW);
  }
  




}

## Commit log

2018-10-13 Update Software/Main/Main.ino
    Added miltiple outputs, wired up to LEDs on a breadboard.
    With fractional time intervals, LEDs quickly lose synchronization.
2018-10-16 Update Software/Main/Main.ino
    Locked the reset of all clocks to the slowest clock, which seems to work ok, but doesn't really reflect the final configuration we're looking for.
    Aside: i realized that beyond a certian point it's going to be difficult to uncover synchronization problems using only the LEDs. It would be better to use audio signals to hear whether things are really synchronized. Furtheremore, withotu some real source generating clock signals, it's hard to fine tune response to changing clock input and (again) hear synchronization problems.
    i.e. I think I really need to get hardware prototyped already.
    [Main.ino]
2018-11-01 finizalized schamatic of prototype
    [Fractional clock divided.kicad_pcb, Fractional clock divided.sch]
2018-11-01 Changed output voltages to 5V.
    Changed all output voltages to 5V.
    [Fractional clock divided.sch]
2018-11-01 Resistor substitution
    Substituting resisitors to reflect what I have at-hand
    [Fractional clock divided.sch]
2018-11-02 Resistor substitution
    Again, substitution to match components I have on-hand
    [_saved_Fractional clock divided.sch]
2018-11-02 Resistor substitutions
    [Fractional clock divided.sch, _saved_Fractional clock divided.sch]
2018-11-03 Fixed LED output
    Fixed a hardware bug with the output LEDs: the current going into the transitior base was not being limited.
    [Fractional clock divided.sch]
2018-11-12 circuit bugfixes
    Circuit bugfixes:
    Added pulldown resistor to the encoder switch
    Changed feedback resistor on the input CV opamp, to keep it within the correct voltage range. My choice (15k) was probably a little conservative - on testing, the voltage seen by the teensy can't go above 2.2V now. Stick with it for now though.
    [Fractional clock divided.sch]
2018-11-13 Intial testing (and bugfixing) of prototype build
    [TestOutputs.ino]
2018-11-20 Adapting old code for new hardware
    Changing the old clock division code I used with breadboarded-teensy to work with the hardware prototype.
    In/out work as expected with my eurorack system, but the clocks rapidly become unsynced.
    When a signal is just passed straight through however, I don't hear any delay.
    Next step is to rewrite, using a master clock following the input, whose sync gets reset every cycle (defined by the top knob).
    [Main.ino, PassTriggerInToOuts.ino]
2018-11-22 Started PulsePredictor class
    Started building a class of objects to relay incoming pulses, and/or form predictions about when future pulses will arrive. untested.
2018-11-23 Pulse thru using PulsePredictor class
    Finished setting up the PulsePredictor class. Managed to get it passing pulses straight through to the output.
    However, I only get proper triggering if I add a >=1ms delay in the loop. I suspect this is because pulses are otherwise too short to trigger my other modules. Next on the to-do list is to make an object to control pulse length.
    [Main.ino]
2018-11-24 ClockDivider/Multiplier
    Added an object to control clock division/multiplication.
    Currently, there's a bug whereby even multiples (e.g. 4 out over 2 in) work ok, but more complex polyrhythms (e.g. 3 out over 2 in) dont give the correct output
    [Main.ino]
2018-11-24 Bug fixed
    Simple bug- fixed.
    Now working as intended, but without dynamic control of paramaters via knobs/CV. That's next on the to do list...
    [Main.ino]
2018-12-02 Length pot control, jitter smoother
    Wired up the length pot to control changes in cycle lengh.
    There werre problems with jitter in the knob voltage - I've tried a simpe fix, but it's bugged. I think because if it throws away a new datapoint on the nth iteration, the next iteration is looking back to that datapoint which should have been thrown away.
    [Main.ino]
2018-12-03 Fixed anti-jitter code
2018-12-03 Reading multiple pots - problematic!
    Upon testing, realized that it's nontrivial to read multiple analog inputs at the kind of speeds i would like. At the moment, if I read fast, there is crosstalk between the channels, presumably because the single Teensy LC ADC isn't working fast enough.
    Need to dig in the code of ornament & crime etc to see how they get around this. Alternative is to change the hardware. (External ADC?)
    [Main.ino]
2018-12-08 Updated pot values for faster readings
    [Fractional clock divided.sch]
2018-12-28 Encoder
    Got readings from encoder, after a little troubleshooting. Next job: actually wire it up to shift/shuffle
2018-12-29 Shift control -Div/Mult mode
    In Div/Mult mode, the encoder now shifts (by integer amounts) our position in the input cycle. (as one might use, for example, to synchronise the cycle starts on input and output clocks.)
2018-12-29 Shuffle Control - Div/Mult mode
    In Div/Mult mode, turning the encoder with the encoder switch pushed down now delays output pulses by 0 to 1 beats.
    Brightness of the shuffle led indicates the extent of shuffle, but the brightness response doesn't seem very linear to me, so it's not exceptionally useful.
    To do: implement CV control over enocder functions.
    [Main.ino]
2018-12-30 CV control
    Made a start on CV control. Reading CV switch assignment.
    To do:
    - Figure out how to calibrate the CV input to recognise 0v in, and scale accoridngly
    - figure out how to route the CV input into the appropriate control signal.
2018-12-30 CV control
    Fleshed out the functions which read the control voltage, and attenuvert it based on the setting of the attenuverter knob.
    There are some (hardware?) issues - e.g then the jack isn't plugged, there's quite a lot of noise on the input.
    I've tidied up the way that the (length and divisions) knobs are read, to make it simpler to add the attenuated control voltage value to the knob reading directly, before scaling to the desired paramater ranges. I've maked the place in the code where that now needs doing.
    Haven't started implemetation of CV control over the encoder functions (shift/shuffle).
    [Main.ino]
2019-01-04 CV control over shift
    I think CV control over shift works now, but I've somehow broken the division/multiplication code. The jitter smoother doesn't seem to perform properly any more (massive lag), and the divider output isn't at all what it should be.
    [Main.ino]
2019-01-04 Revert "CV control over shift"
    This reverts commit d19ce64adabfa426d813e32895e127e230ccecf6.
    [Main.ino]
2019-01-04 Revert "CV control"
    This reverts commit 9678daa802b3669ac48b2bf6e4cd711890e735c7.
    [Main.ino]
2019-01-04 Restore Dec31st commit
    REstored the Dec 31st commit line-by line, with a few ommisions, tidying a few things up on the way.
    At first, div/mult code worked ok but not CV control. In trying to fix that, I think I re-introduced the issue: it definitely seems to be related to the jitter smoother.
    Jitter smoother seems to be reading the wrong input - not picking up the signal from the knob.
    Removed the jitter smoothing for now.
    [Main.ino]
2019-01-05 Jitter Smoother bug fixed
    Fixed the bug with the jitter smoother
    [Main.ino]
2019-01-05 CV control over shift and shuffle
    CV control implemented over shift / shuffle.
    A few caveats:
    - We don't have enough switch positions currently to allow both shift and shuffle as options. I hope to fix that in the next hardware iteration...
    - The effect of noise in the CV input in causing big problems (constant skipping between paramater values.) I think we probably need more sophisticated smoothing
    [Main.ino]
2019-01-06 CV jitter fix
    Smoothed out noise/jitter in CV control over Shift/Shuffle functions, which actually came from reading the attenuverter/knob voltage without smoothing.
    [Main Backup 2019_1_5.ino]
2019-03-14 Identified bug in CV control over shuffle, started plumbing euclidean generator into main()
    Implemented basic knob control for the euclidean pattern generator
    started putting calls to the euclidean pattern generator in the main code cycle
    however, found a bug in CV control over fractional shuffle: When we increase the CV/shuffle amount in between the [time the pulse would be at with 0 shuffle] and [time the pulse should be at with the old shuffle amount prior to knob turn], the output in that cycle gets lost. (testing with 1 hit/cycle]
    [Main.ino]
2019-03-15 bug hunting
    I've still failed to find the source of the bug: output pulses (clock divider mode) stop while the CV attenuverter or CV in signal is rapidly altered.
    I think the right PositionInOutputCycle is set by DividerMultiplier::CalculateOutputTimesMidCycle, but when I look in DividerMultiplier::ShouldWeOutputMainPulse, it often seems wrong.
    One thing to consider: is it faulty that we only loop the Output cycle back to the beginning when the Input cycle resets?
    [Main.ino]
2019-03-22 Bug fix
    Fixed the bug where output beats could be missed immediately after the shuffle CV was altered. Did some tidying up along the way.
    There's at least one remaining bug: after a certain point we stop getting (divider/multiplier) output pulses, even though the PositionInOutputCycle value keeps cycling as expected
    [Main.ino]
2019-03-22 Fixed micros() rollover bug
    Implemented a more sensible way of handing micros() rollover.
    However, I haven't testeed up until the rollover point. I just know that a previous bug where output stopped after a a few minutes no longer occurs.
    I also changed the polarity of CV effect on fractional shuffle - it's more intuitive this way.
    [Main.ino]
2019-03-23 Euclidean Rhythm generation
    Finished the euclidean rhythm generation code, and plugged it into the main loop - it now works as expected, with knob and cv control.
    To do
    - test CV control over shift works
    - Write something to handle changes between Euclidean and Mult/Div modes
    - Write something to force cycle resets (in anticiaption of the next hardware revision, which I think should have a cycle reset in)
    - Think about what we can do when hits>quantization
    - think about more complex beat snapping, for something like the euclidean mode but not quite
    [Main.ino]
2019-03-25 gate mode + various other
    Checked that CV control over shfit works ok.
    Implemented seamless switching between modes (euclidean / division) from the front panel
    Implemented switchable (from the front panel) gate out mode, in which the Main out outputs gates rather than triggers
2019-03-25 Euclidean mode - snap to closest point
    Added a "snap to closest point" feature in the euclidean mode. Not clear yet whether it really adds anything musically over the regular euclidean mode...
    [Main.ino]
2019-03-26 Schematic rework for PCB deisign
    Updated schematic based on new interface design. Note lots of pin changes. This will be developed into front panel design. Im going to try and design a single PCB first, before resorting to a multi-layer sandwich.
    [Fractional clock divided.kicad_pcb, Fractional clock divided.sch, Fractional clock divider PCB1.kicad_pcb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]
2019-04-12 PCB design
    Finalized PCB design.
    [Fractional Clock divider PCB1 bottom board-B.Cu.gbr, Fractional Clock divider PCB1 bottom board-B.Mask.gbr, Fractional Clock divider PCB1 bottom board-B.Paste.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]
2019-04-12 PCB renders, panel mockup
2019-04-26 Code update to reflect PCB design
    Updating code to reflect
    -changes in pins
    -new CV assignment method
    -new mode slect configuration
    Seems to work, but having assembled the first version of the PCB there's quite a few errors to fix before we take development any further...
    [Fractional clock divider PCB1.csv, Fractional clock divider PCB1.sch]
2019-04-27 PCB rework
    Reworked PCB design to
    -Add PCB panel
    -correct knob orientation
    -rearrange panel to make more space for labels
    -easier-to-solder footprints for jacks and transistors
    -correct silkscreen-label switcheroos
    -correct opamp connections
    -increase brightness of output LEDs
    -give more clearence to power header and mark orientation on PCB
    also cleaned up old obsolete files.
    PCBs ordered from JLCPCB
    [Fractional Clock divider PCB1 bottom board-B.Cu.gbr, Fractional Clock divider PCB1 bottom board-B.Mask.gbr, Fractional Clock divider PCB1 bottom board-B.Paste.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]
2019-05-23 Code update to reflect second PCB design
    - Updated CV destination selection code to match new PCB+panel design
    - Found that potentiometer backlash and non-linearity precented knob pointers from matching panel ticks. To solve this, I implemented a very janky calibration procedure, which prints output over serial USB, which then needs processing with a separate C++ code to generate lookup tables that can be re-inserted into the teensy code
    - Updated code to allow "divisions" = 0 ( => no output, in either mode. )
    - reduced severity of anti-jitter correction on the knobs - readings are much less noisy now that 100k pots have been replaced with 10k
    - try and increase the brightness of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
    [Fractional clock divider PCB1.csv, Fractional clock divider PCB1.kicad_pcb, Fractional clock divider PCB1.sch]
2019-05-23 Added functionality to reset input
    Added code to make use of the reset input
    [Main.ino]
2019-05-25 Bug fixes in shuffle and CV handling
    -changed the guts of the shuffle handling to make led brightness better behaved at shuffle = 1. (Still to do: lookup tables for more linear LED brightness)
    -reduced smoothing on the CV input.
    [Main.ino]
2019-05-25 Shuffle LED linearity
    Impletemented more linear scaling of the shuffle LED, using a LUT
2019-05-25 Simultaneous Divider + euclidean modes
    Now both the divider/multiplier and euclidean modes both run in paralellel always. The mode switch just determines whether the outputs of each make it to the the output jack. The middle setting of the mode switch outputs both, and I think this generates musically useful output.
    I had to rewrite the way that the euclidean code handles shift, so that the phase of the cycles in the two different modes (as indicated by the "cycle" out) doesn't drift.
    There might still be a bug somewhere which allows the phases to shift still, but I haven't managed to reproduce it, and I fixed a bug which I think might have caused the problem.
    Some issues to think about: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
    [Main.ino]
